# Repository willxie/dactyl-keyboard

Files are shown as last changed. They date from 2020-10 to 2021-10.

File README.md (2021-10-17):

# The Dactyl-ManuForm Keyboard - Python 3 - Cadquery
This is a fork of [Dactyl-Manuform](https://github.com/tshort/dactyl-keyboard) by Tom Short, which itself is a fork of [Dactyl](https://github.com/adereth/dactyl-keyboard) by Matthew Adereth, a parameterized, split-hand, concave, columnar, ergonomic keyboard.

While the code structure remains comparable to the original, Clojure and OpenSCAD have been replaced by Python and cadquery/OpenCASCADE.  The predecessors were exceptional contributions to the ergo keyboard community by the authors but used a rather esoteric programming language, Clojure, and a relatively inconsistent geometry engine, OpenSCAD.  My hope is that by converting the code the community will have an easier time modifying and evolving this design.  

## Collaborations and Donations
I decided to start accepting donations to help offset some of the prototyping costs and development time.  There are 2 ways to contribute to this project:

### Purchase a kit or keyboard from https://www.ergohaven.xyz/
I am also supported by [ergohaven](https://www.ergohaven.xyz/).  The Dactyl-Manuforms are generated from this repository.  After working with the owner on additions to support new features we decided to collaborate to evolve the designs they can offer and to support my work.  

### Donate directly
I opened Liberapay and Ko-fi accounts to accept donations.  It is obviously not necessary, but is appreciated.  If you do donate and have something specific you really want to see, please let me know. I want to be very open that I can't promise to complete all requests as there are many reasons like engine capabilities and generator construction that can make certain features unfeasible, but I will do my best to improve this repo for you and the ergo keyboard community.

Donate using Liberapay (https://liberapay.com/joshreve/donate)



## Helpful Feedback
At this point there has been tons of feedback form the community and I greatly appreciate it.  While I can only work on this in my free time, I do my best to respond to anyone who posts a comment or question.  Feedback on issues or just possible new features is always welcome.

## Updated Geometry Engine, generating STEP files
As part of the effort to create a new engine I converted the code to cadquery/OpenCASCADE.  While OpenSCAD has provided an open source 3D engine that is extremely popular, it frankly creates barely passable STLs when you have complex geometry.  After being extremely frustrated trying to fix the mesh I realized it is just not a stable engine to create high quality files.  OpenCASCADE is extremely powerful but requires extensive detail to operate.  cadquery provided an excellent platform to run a stable geometry engine with a simplified API. 

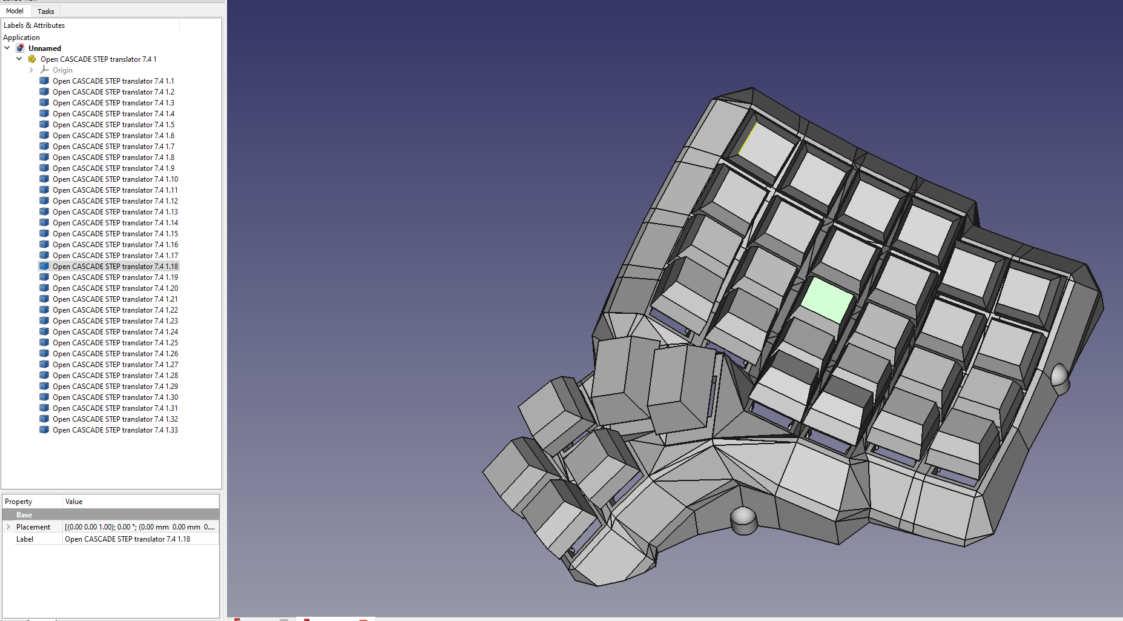
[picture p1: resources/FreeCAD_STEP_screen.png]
STEP File in FreeCAD


## Added Features

### Docker Autobuild
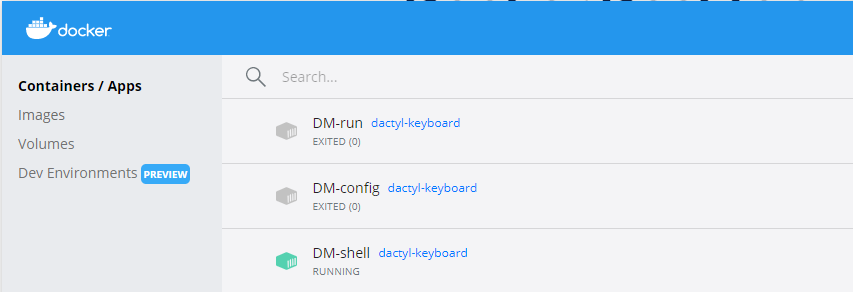
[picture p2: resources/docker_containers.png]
Docker Support!


At the excellent suggestion of [martint17r](https://github.com/joshreve/dactyl-keyboard/issues?q=is%3Apr+author%3Amartint17r) 
I have added docker configurations with a Windows batch file to assist with getting setup. 
If you have 
[docker desktop](https://www.docker.com/products/docker-desktop) installed, the batch file will create the 
dactyl-keyboard image and 4 containers:

- DM-run: runs `dactyl_manuform.py`, 
- DM-config: runs `generate_configuration.py`
- DM-shell: starts an interactive session to manually run from shell
  - tip: run bash after entering to get a better shell environment
- DM-release-build: runs `model_builder.py` to generate a number of keyboard variants

All apps bindmount the `src` and `things` directory to allow editing in the host and running in the
container.  While not exactly hard drive space efficient, this hopefully helps those having issues getting
cadquery running and prevents local Python conflicts.  It works well on my computer, but I don't use
docker often, so please let me know if you find any issues with the approach.

### Refactored

Your settings are now created by `generate_configuration.py` or by direct modification of the `run_config.json` file.  
This allows you to save `run_config.json` to share your configuration.

Additionally, the OpenSCAD/solid python and OpenCASCADE/cadquery versions are merged with separate helper functions 
to decouple the generator from the target library.  This also lets me stay sane by only modifying one file for most updates.
Running `dactyl_manuform.py` will automatically load the `run_config.json` file. 

### Everyone gets a thumb cluster!

Added support of for the thumb clusters in the [carbonfet Dactyl library](https://github.com/carbonfet/dactyl-manuform).
These are the "mini" and "carbonfet" thumb clusters. Additional trackball cluster added as well more info to be added after additional build and debug time.

Feel free to try them out with by setting `'thumb_style'` to 
`'DEFAULT'`, `'MINI'`, `'CARBONFET'`, `'MINIDOX'`, `'TRACKBALL_ORBYL'`, and `'TRACKBALL_CJ'`.

Trackball features accommodate a [Perixx PERIPRO-303](https://smile.amazon.com/gp/product/B08DD6GQRV/).  Others may fit, but this was the target ball diameter for the design.  It is a little smaller than a Ploopy to try to fit better in the cluster.

Rendered and actual images to be added in future commits.

### Clippable switch mounting

Tired of hot glue and constraining the socket with "nubs"?  I've added an adjustable undercut for using the clips on 
the sockets.  May require some tweaking and little filing, but I have my DM built without any glue and you can too.  
Just use `plate_style = 'UNDERCUT'`.  I've also added an improved local undercut using `plate_style = 'NOTCH'`.

### Kailh Hotswap
Added a new switch for hot swap and a way to include any additional geometry in the key plate by use of an imported file.
For hot swap just use `plate_style = 'HS_NOTCH'`, `plate_style = 'HS_HOLE'`, or `plate_style = 'HS_NUB'`.  
To import an arbitrary geometry set the `plate_file = None` and `plate_offset = 0.0`.  
The file must be .step for OpenCascade / cadquery and .stl for openSCAD / solid python.  
The zero reference should be the key center (XY), and the top of the plate (Z).  
Plate offset is a Z-axis translation for minor adjustments without modifying the geometry file.  

**DISCLAIMER:  I have not built the hot swap version and cannot speak to the geometry.  I found it running around in various places and don't know the origin.  At least one user has claimed it works.**  

If you know the origin I would like to credit the originator.  If you test it I'd love to know how well it works or if you come up with a better geometry I'm happy to add it.  

Message me on Reddit u/j_oshreve if you are really stuck.  I don't have much time to help, but can answer the occasional question.  Also feel free to put in a pull request if you come up with something crafty and want to give others access to it.

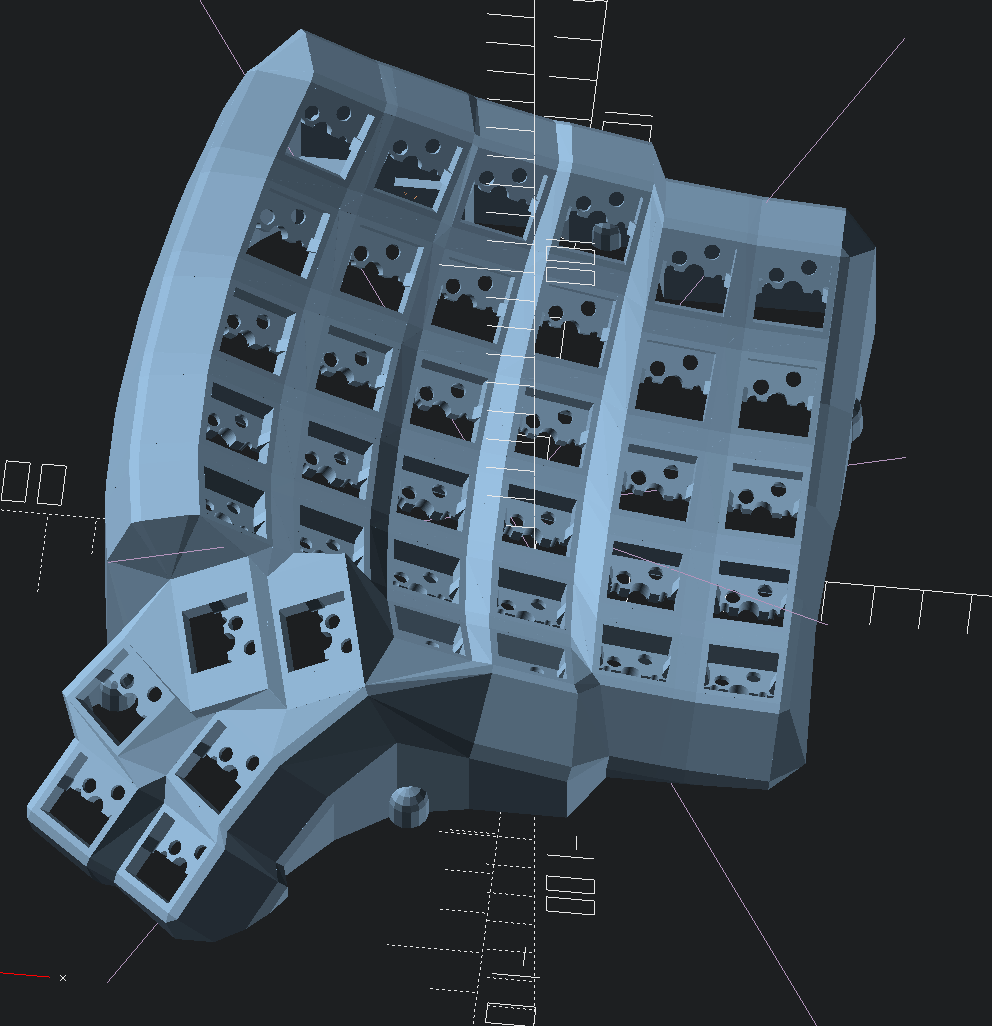
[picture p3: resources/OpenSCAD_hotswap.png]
Hot Swap in OpenSCAD


### Multiple Controller Mounts

Added an external mount for a separate controller tray.  Looks to work with lolligag's controller trays / holders:

- [Promicro V1](https://dactyl.siskam.link/loligagger-external-holder-promicro-v1.stl)
- [Promicro V2](https://dactyl.siskam.link/loligagger-external-holder-promicro-v2.stl)
- [Elite-C V1 ](https://dactyl.siskam.link/loligagger-external-holder-elite-c-v1.stl)

Just use `controller_mount_type = 'EXTERNAL'`.

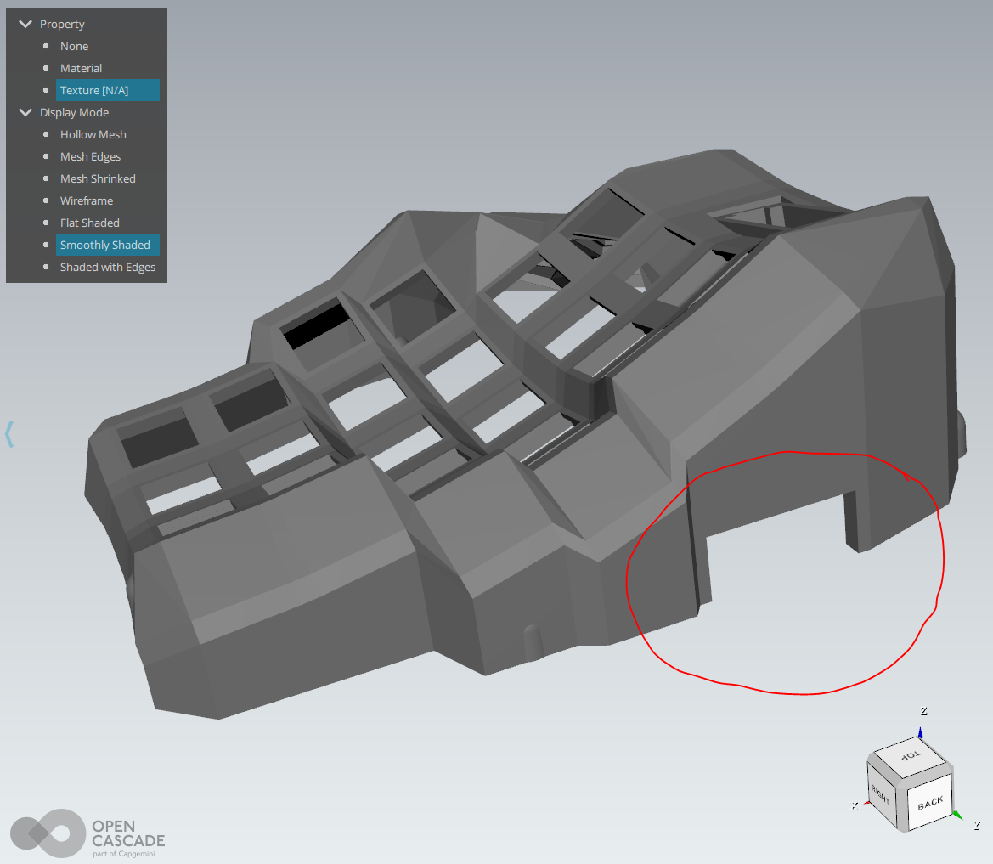
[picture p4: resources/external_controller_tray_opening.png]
Controller tray opening

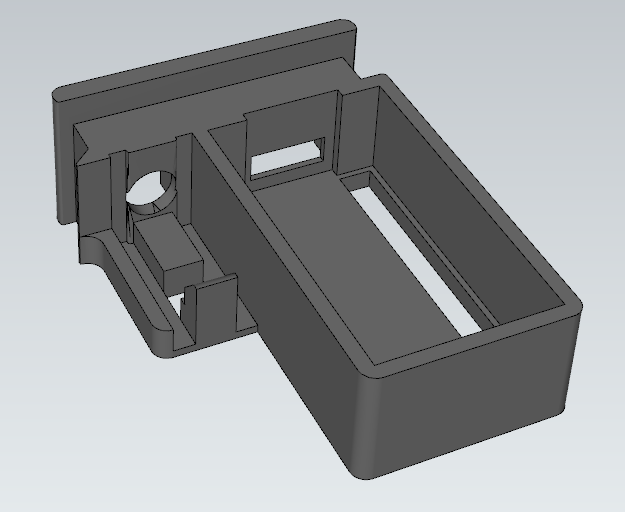
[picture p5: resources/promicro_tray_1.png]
Tray 1

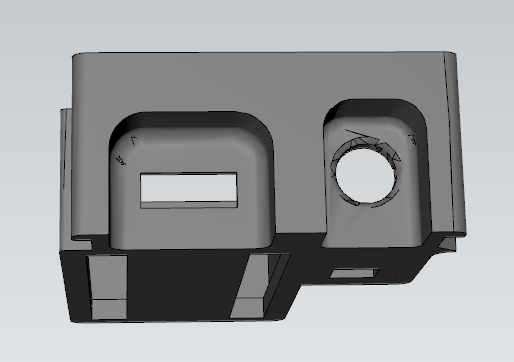
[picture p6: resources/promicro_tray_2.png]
Tray 2


This is a new feature so any feedback is appreciated.  If you have issues, message me on Reddit and I will try to help correct them.

### OLED Display Mount

Added 3 OLED mounts.  Have printed them stand alone with success.  I suggest clip, but it may require some tweaks based on your printer (over vs under sized).

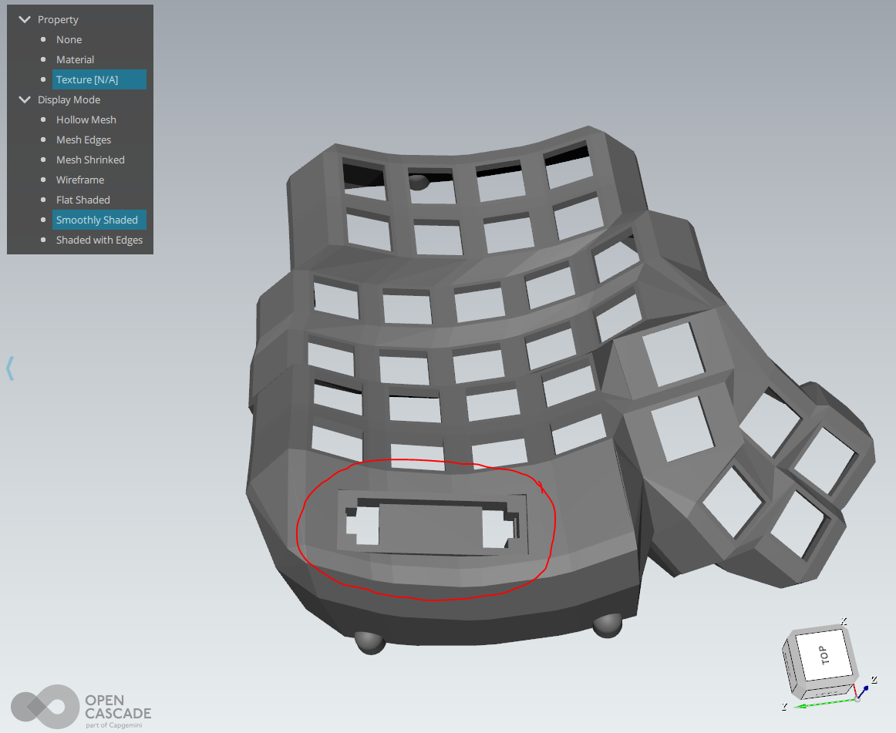
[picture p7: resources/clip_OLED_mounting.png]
OLED Clip Mounting

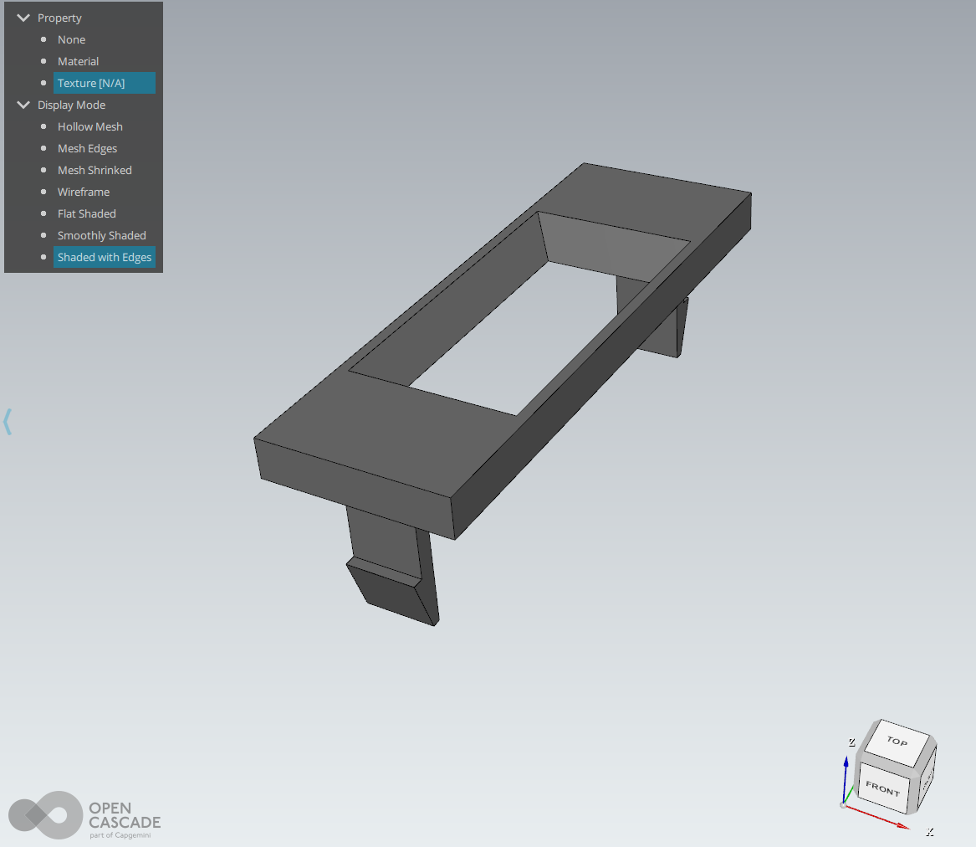
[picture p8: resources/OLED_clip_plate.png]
OLED Clip Plate


`oled_mount_type = 'CLIP'` creates an opening to set the OLED with a clip on face plate to hold it down.  This is the preferred mounting, but needs the OLED to have a removable connection.  

`oled_mount_type = 'SLIDING'` creates an opening such that you can slide the screen up through the back and into place.  Needs a piece of foam or a bit of glue to lock in place.

`oled_mount_type = 'UNDERCUT'` creates an opening with an undercut to create whatever custom holder you want.  Will not work without additional part creation from the user.

This is a new feature so any feedback is appreciated.  If you have issues, message me on Reddit and I will try to help correct them.  

### Screw Post Locations

You can now have slightly better control of screw mounts.  Set to `'screws_offset':'INSIDE'`, `'screws_offset':'OUTSIDE'` or `'screws_offset': 'ORIGINAL'` to control screw locations relative to the wall. 
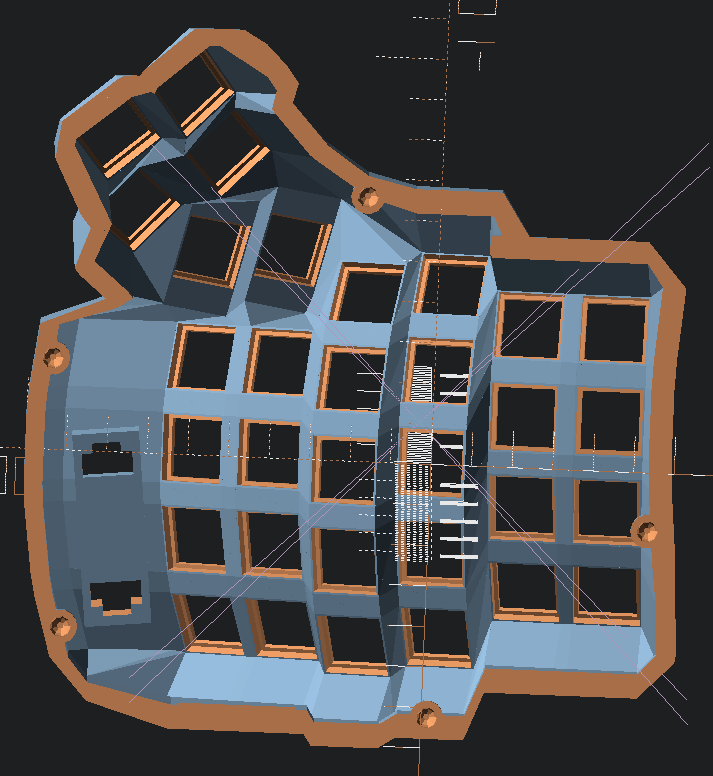
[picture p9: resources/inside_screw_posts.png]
Inside Screws


I am planning to deprecate outside and original at some point.  I don't see the need to carry all of them and the hidden look the best.  If you disagree feel free to let me know and I may keep a second form.

## Status / Future
This is now a bit of a monster of many minds and yet continues to bear fruit.  
I plan to continue to use this code to try new geometries and features to share for the foreseeable future.

## Installation

There are three different environments in which you can run this application. Depending on which you choose, the installation process will vary.

- [Docker Environment](#docker-environment-installation)
- [Conda Environment](#conda-environment-installation)
- [Python Environment](#python-environment-installation)

### Docker Environment Installation

Running the application with Docker is the most convenient way to do so. In addition to a straightforward installation, this also allows you to generate models in the background without having to keep a shell open.

*Note:* If you are using Windows, see [Docker Autobuild](#docker-autobuild).

Before you proceed, ensure you have installed [Docker](https://www.docker.com/) and the `docker` command is available from your terminal.

There are two tools you can use to help manage the Docker containers associated with this project. 

#### Make

If you prefer, you can use `make` to manage the containers. Type `make help` to see the available commands.

#### Bash Script

The `dactyl.sh` bash script provides a CLI to manage the containers. Type `./dactyl.sh --help` to see all CLI options.

In addition to the CLI you can run `./dactyl.sh` without any arguments to use an interactive menu. 

Upon running the script, you will be prompted to build the dactyl-keyboard Docker image.

Once the image is built, you can choose which containers to run on an as-needed basis. In general, you can start, stop, rebuild, inspect, and remove the containers via the CLI/Menu. 

You can also remove all of the Docker artifacts by running the included uninstaller.

*Tip:* Run `./dactyl.sh shell --session` to jump into a bash session inside of the shell container.

### Conda Environment Installation

After the Docker installation, Anaconda is the next best option. Before you begin, ensure you have installed [Anaconda](https://docs.anaconda.com/anaconda/install/index.html) and the `conda` command is available from your terminal.

You can install all of the dependencies by hand, but you can automate the install by running the bash script `./conda.sh`. This will create a python 3.7 environment named `dactyl-keyboard` and install all of the required dependencies.

If you would like to install into a conda environment manually, check the bash script to see all of the required commands.

If you would like to remove the conda artifacts, run `./conda.sh --uninstall`.

### Python Environment Installation

You can install the application in a regular python environment, but it is not recommended. You will not be able to take advantage of the updated geometry generated by the CadQuery engine, as this is only available via the Docker/Anaconda installation.

**Setting up the Python environment - NEW**
* [Install Python 3.X](https://www.python.org/downloads/release/python-385/) or use your [favorite distro / platform (Anaconda)](https://www.anaconda.com/products/individual) 
* It is advisable, but not necessary, to setup a virtual environment to prevent package/library incompatibility 
* [Install Numpy](https://pypi.org/project/numpy/), easiest method is `pip install numpy` or `pip3 install numpy` on linux.
* [Install dataclasses_json](https://pypi.org/project/dataclasses_json/), easiest method is `pip install dataclasses-json` or `pip3 install dataclasses-json` on linux.

**cadquery install**
* [Install scipy](https://pypi.org/project/scipy/), easiest method is `pip install scipy` or `pip3 install scipy` on linux.
* [Install cadquery](https://github.com/CadQuery/cadquery), many options (see link), but easiest method is `conda install -c conda-forge -c cadquery cadquery=2`.  Props to the creators/maintainers, this has the power of Open CASCADE with nearing the simplicity of OpenSCAD.

**OpenSCAD install**
* [Install SolidPython](https://pypi.org/project/solidpython/), easiest method is `pip install solidpython` or `pip3 install solidpython` on linux.
* [Install OpenSCAD](http://www.openscad.org/)

## Generating the design

**Generating the design - UPDATED**
* ~~Run `python dactyl_manuform_cadquery.py` or `python3 dactyl_manuform_cadquery.py`~~ 
* ~~Run `python dactyl_manuform.py` or `python3 dactyl_manuform.py`~~
* Run `generate_configuration.py` or directly edit `run_config.json` to configure the design
* Run `dactyl_manuform.py` to create the geometry (ENGINE variable in run determines method)
* This will regenerate the `things/` files (or in subdirectory if defined in config)
    * `*left.*`
    * `*right.*`
    * `*plate.*`
    * `*oled_clip.*` (if applicable)
    * `*oled_clip_test.*` (if applicable)
* Use OpenSCAD to open a `.scad` file
* Use FreeCAD or other application to open a `.step` file
* Make changes to design, repeat run step
* When done, use OpenSCAD or FreeCAD to export STL files

**The majority of the the rest of the below content is as defined by previous authors, except where noted.**

## Origin
Imgur

The main change is that the thumb cluster was adapted from the [ManuForm keyboard](https://github.com/jeffgran/ManuForm) ([geekhack](https://geekhack.org/index.php?topic=46015.0)). The walls were changed to just drop to the floor. The keyboard is paramaterized to allow adjusting the following: 

* Rows: 4 - 6 
* Columns: 5 and up
* Row curvature
* Column curvature
* Row tilt (tenting)
* Column tilt
* Column offsets
* Height

## Assembly

### Printing
Pre-generated files can be opened in OpenSCAD or FreeCAD and exported to STL.  Bottom plate is available as a step file or dxf for cadquery or a .scad file to be exported from OpenSCAD.

### Wiring

Here are materials tshort used for wiring.

* Two Arduino Pro Micros
* [Heat-set inserts](https://www.mcmaster.com/#94180a331/=16yfrx1)
* [M3 wafer-head screws, 5mm](http://www.metricscrews.us/index.php?main_page=product_info&cPath=155_185&products_id=455)
* [Copper tape](https://www.amazon.com/gp/product/B009KB86BU)
* [#32 magnet wire](https://www.amazon.com/gp/product/B00LV909HI)
* [#30 wire](https://www.amazon.com/gp/product/B00GWFECWO)
* [3-mm cast acrylic](http://www.mcmaster.com/#acrylic/=144mfom)
* [Veroboard stripboard](https://www.amazon.com/gp/product/B008CPVMMU)
* [1N4148 diodes](https://www.amazon.com/gp/product/B00LQPY0Y0)
* [Female RJ-9 connectors](https://www.amazon.com/gp/product/B01HU7BVDU/)

I wired one half using the traditional approach of using the legs of a diode to form the row connections. 
(I'm not great at soldering, so this was challenging for me.)
For this side, I used magnet wire to wire columns. That worked okay. 
The magnet wire is small enough, it wants to move around, and it's hard to tell if you have a good connection.

Imgur

For another half, I used stripboard for the row connections. 
This allowed me to presolder all of the diodes. 
Then, I hot-glued this in place and finished the soldering of the other diode ends. 
I like this approach quite a lot. 
Connections for the diodes were much easier with one end fixed down. 
On this half, I also used copper tape to connect columns. 
This worked a bit better than the magnet wire for me. 
For a future version, I may try just bare tinned copper wire for columns (something like #20). 
With the stripboard, it's pretty easy keeping row and column connections separate.

Imgur

Note that a telephone handset cable has leads that are reversed, so take this into account when connecting these leads to the controller.

The 3D printed part is the main keyboard. 
You can attach a bottom plate with screws. 
The case has holes for heat-set inserts designed to hold 3- to 6-mm long M3 screws. 
Then, I used wafer-head screws to connect a bottom plate. 
If wires aren't dangling, a bottom plate may not be needed. 
You need something on the bottom to keep the keyboard from sliding around. 
Without a plate, you could use a rubber pad, or you could dip the bottom of the keyboard in PlastiDip.

For more photos of the first complete wiring of v0.4, see [Imgur](http://imgur.com/a/v9eIO).

This is how the rows/columns wire to the keys and the ProMicro
Wire Diagram

#### Alternative row-driven wiring diagram for ProMicro:

NOTE: you also make sure the firmware is set up correctly (ex: change row pins with col pins)

Left Wire Diagram

Right Wire Diagram

### Firmware

Firmware goes hand in hand with how you wire the circuit. 
I adapted the QMK firmware [here](https://github.com/tshort/qmk_firmware/tree/master/keyboards/dactyl-manuform). 
This allows each side to work separately or together. 
This site also shows connections for the Arduino Pro Micro controllers.

## License

General Code Copyright © 2015-2021 Matthew Adereth, Tom Short, and Joshua Shreve
Mini thumb cluster Copyright © 2015-2018 Matthew Adereth, Tom Short, and Leo Lou
Carbonfet thumb cluster © 2015-2018 Matthew Adereth, Tom Short, and carbonfet (github username)

The source code for generating the models (everything excluding the [things/](things/) and [resources/](resources/) directories is distributed under the [GNU AFFERO GENERAL PUBLIC LICENSE Version 3](LICENSE).  The generated models and PCB designs are distributed under the [Creative Commons Attribution-NonCommercial-ShareAlike License Version 3.0](LICENSE-models).

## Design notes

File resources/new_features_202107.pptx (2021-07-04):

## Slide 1

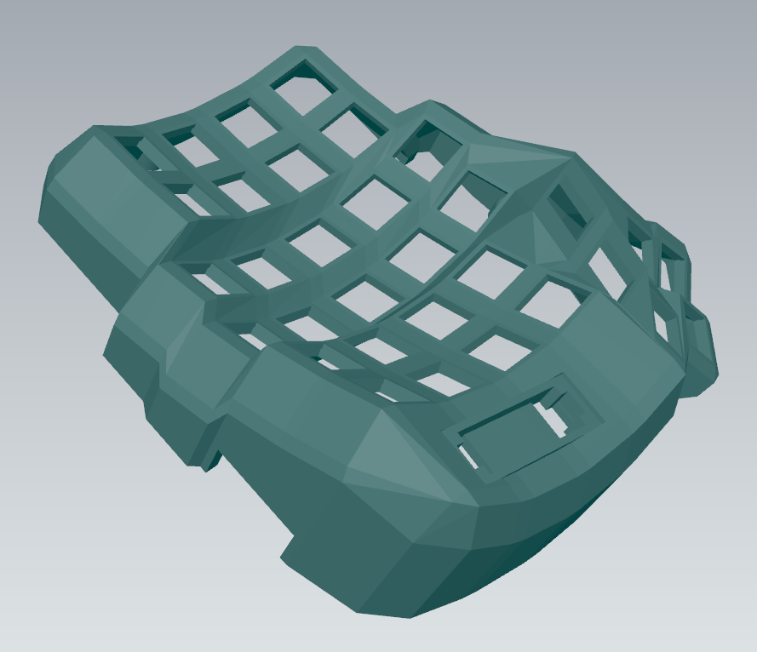
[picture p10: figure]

Controller Tray Interface

OLED Mounting

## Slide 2

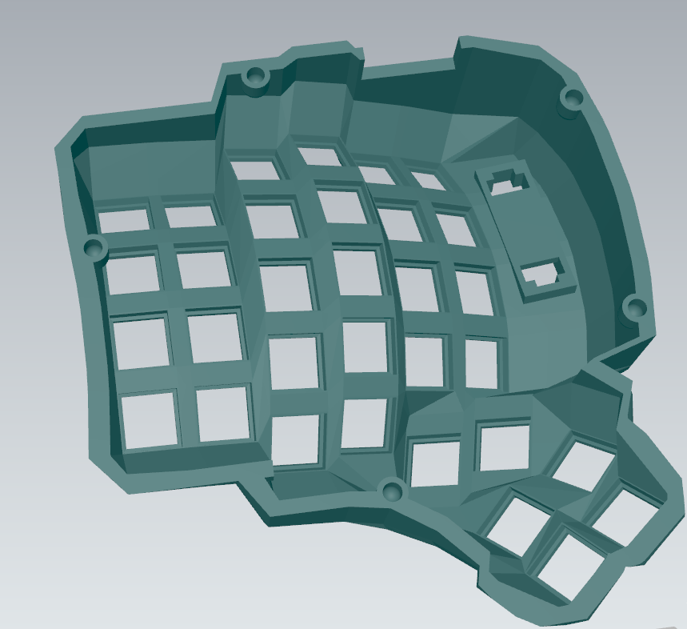
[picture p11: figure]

Controller Tray Interface

OLED Mounting

Internal Mount Screws

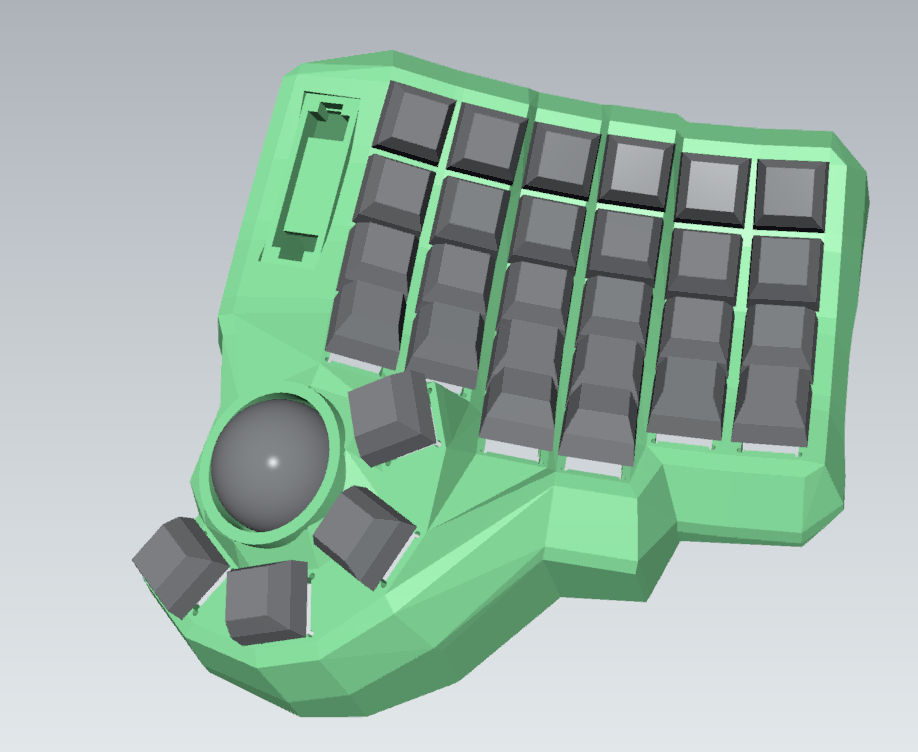
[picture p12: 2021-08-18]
resources/Trackball_JS_Cluster.PNG

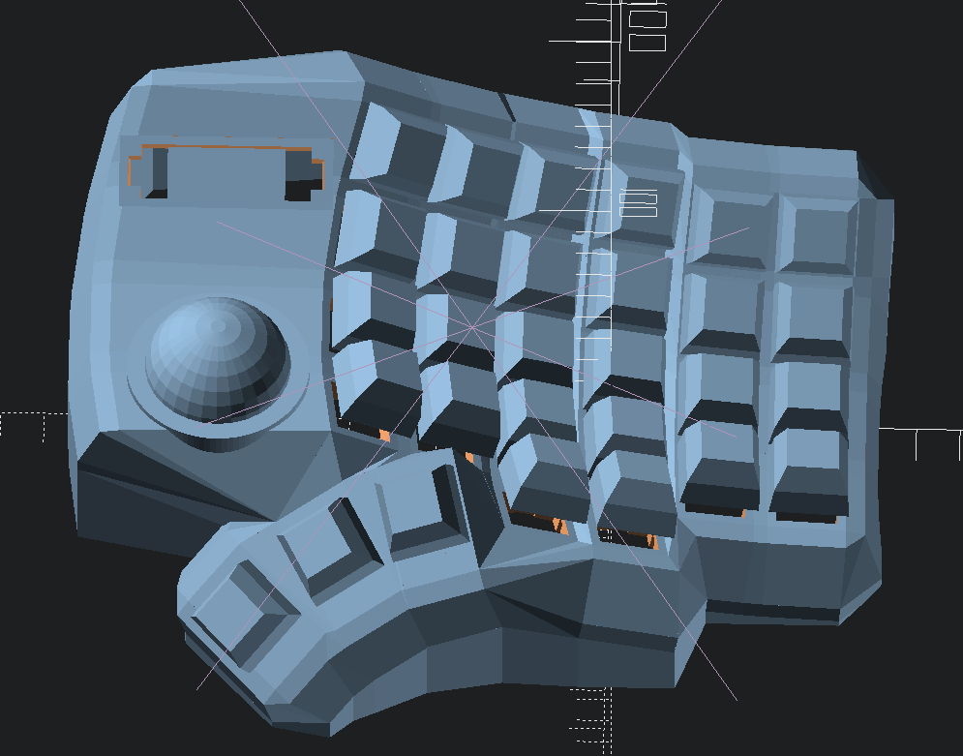
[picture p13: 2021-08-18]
resources/trackball_in_wall.png

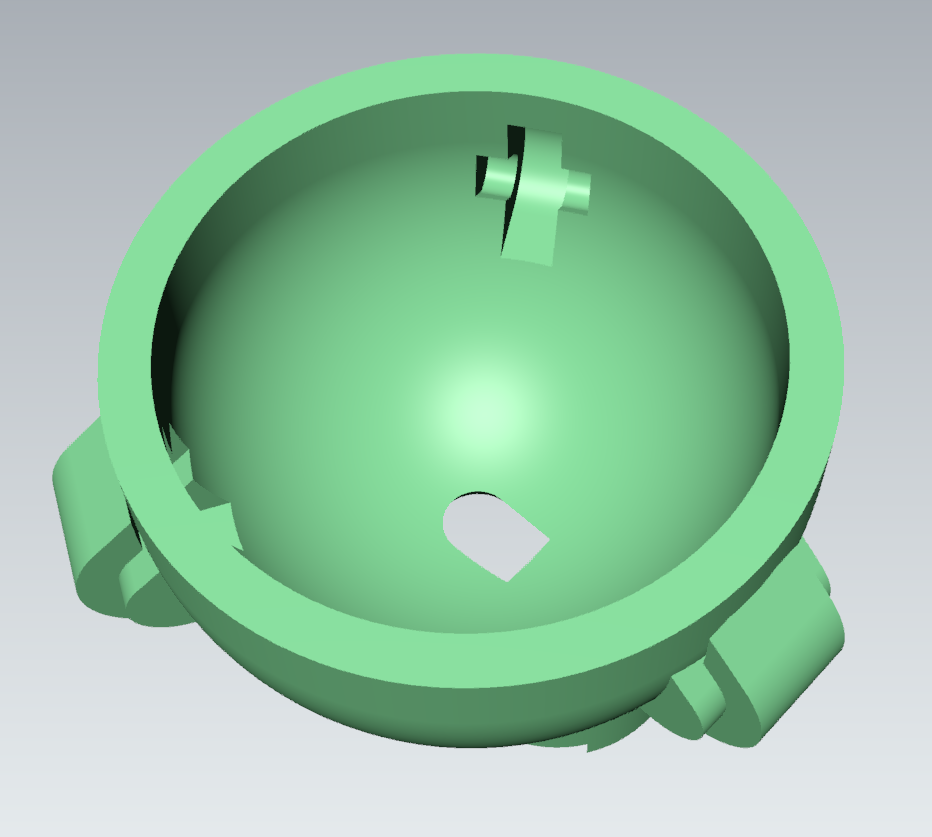
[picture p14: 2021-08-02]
resources/Trackball_socket.png

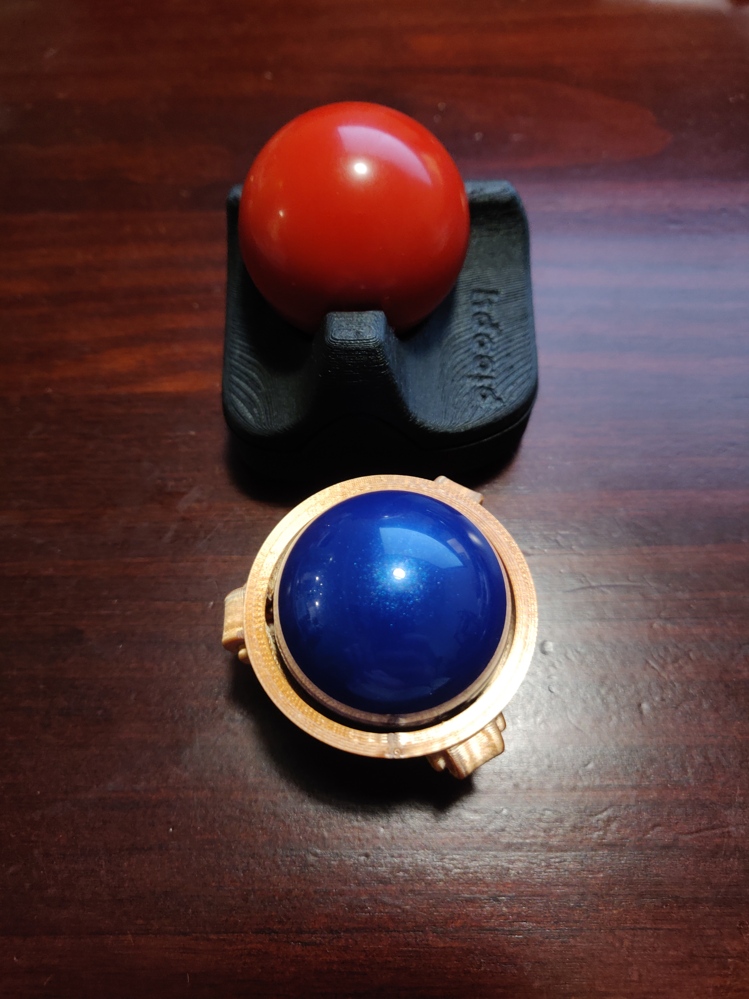
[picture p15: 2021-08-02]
resources/Trackball_socket_pic.jpg

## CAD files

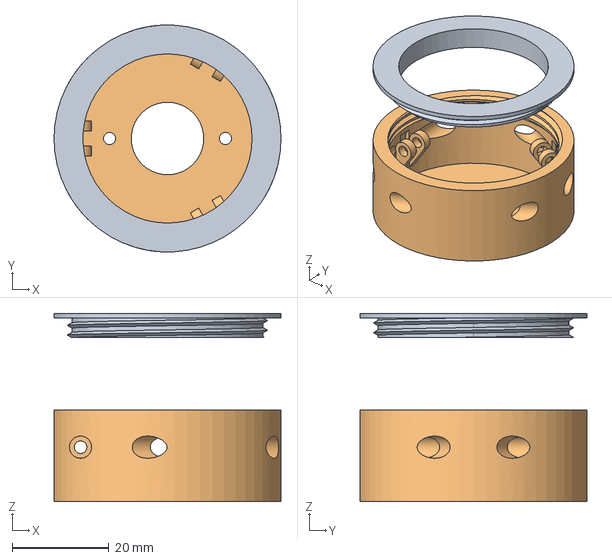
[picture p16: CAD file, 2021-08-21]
src/parts/trackball_mount.step
47.0 x 47.0 x 39.0 mm
Top
Bottom (1)

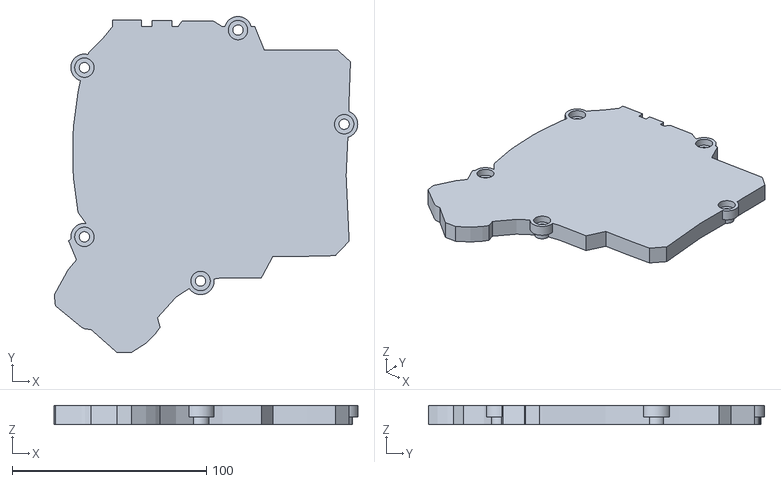
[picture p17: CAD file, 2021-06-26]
things/base_JAS.stl
156.4 x 173.1 x 10.0

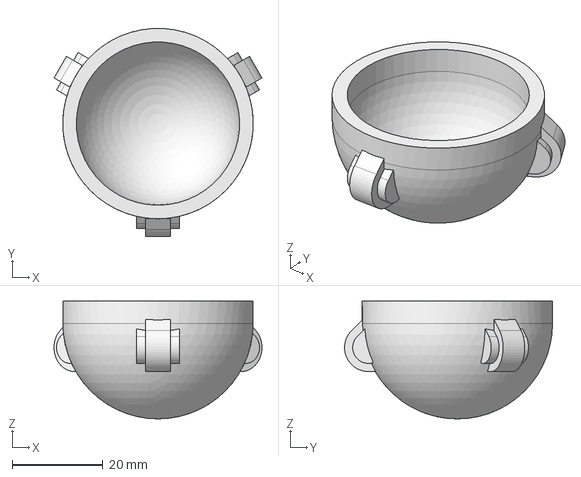
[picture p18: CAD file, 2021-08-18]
src/parts/trackball_socket_body_34mm.step
45.9 x 45.9 x 26.0 mm

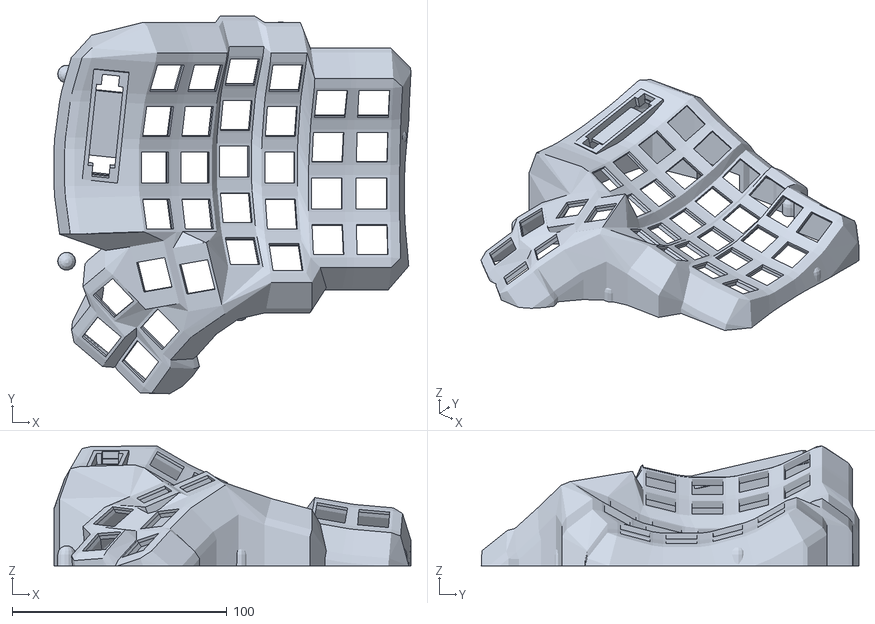
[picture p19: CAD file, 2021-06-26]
things/right_py.stl
166.3 x 175.9 x 55.9

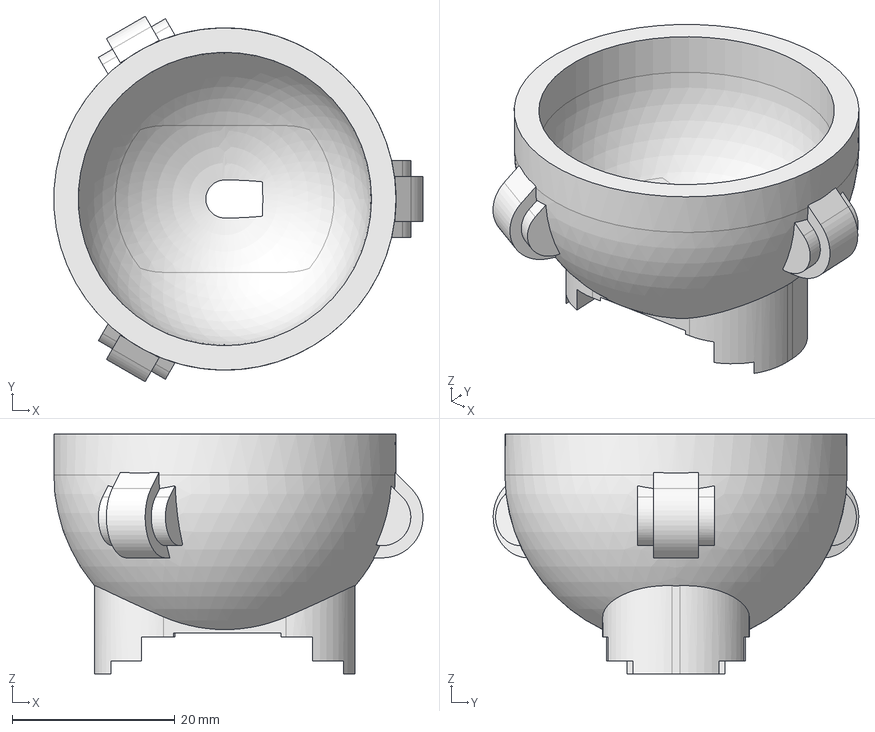
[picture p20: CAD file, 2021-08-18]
src/parts/trackball_fused_34mm.step
45.3 x 44.9 x 29.4 mm

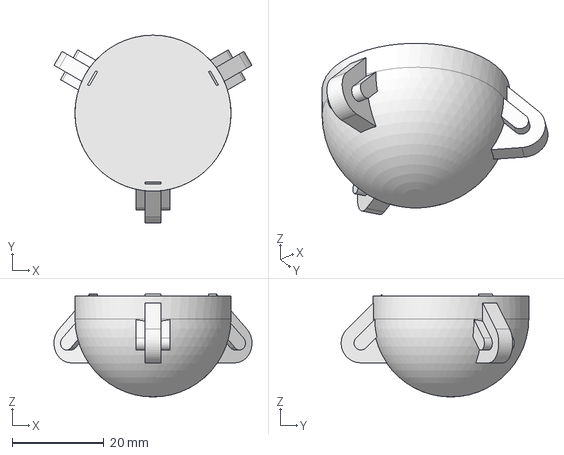
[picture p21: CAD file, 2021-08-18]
src/parts/trackball_socket_cutter_34mm.step
43.2 x 40.9 x 22.4 mm

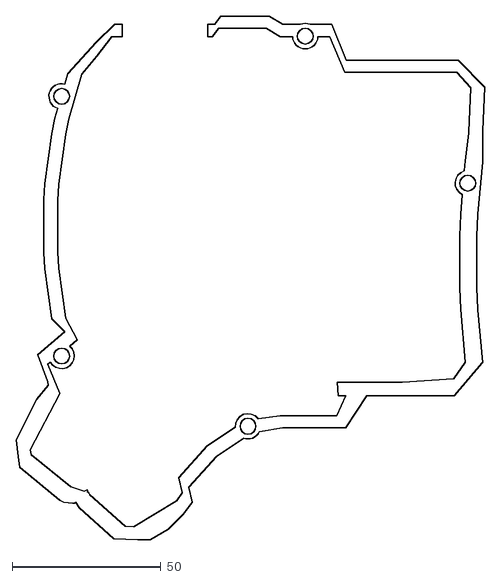
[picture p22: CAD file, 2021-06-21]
things/plate_og_py.dxf
157.4 x 175.9

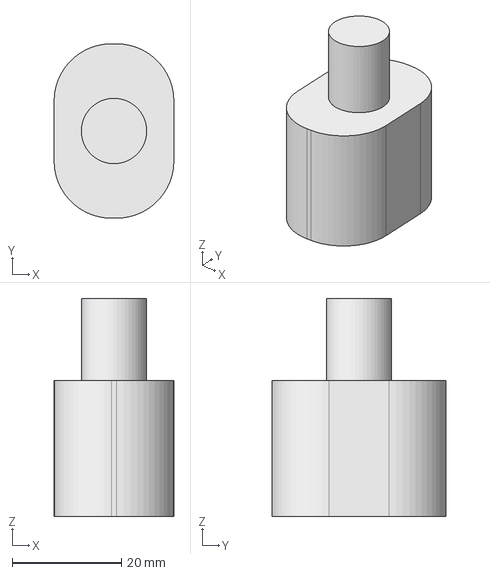
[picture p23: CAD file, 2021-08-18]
src/parts/trackball_sensor_cutter.step
22.0 x 32.0 x 40.0 mm

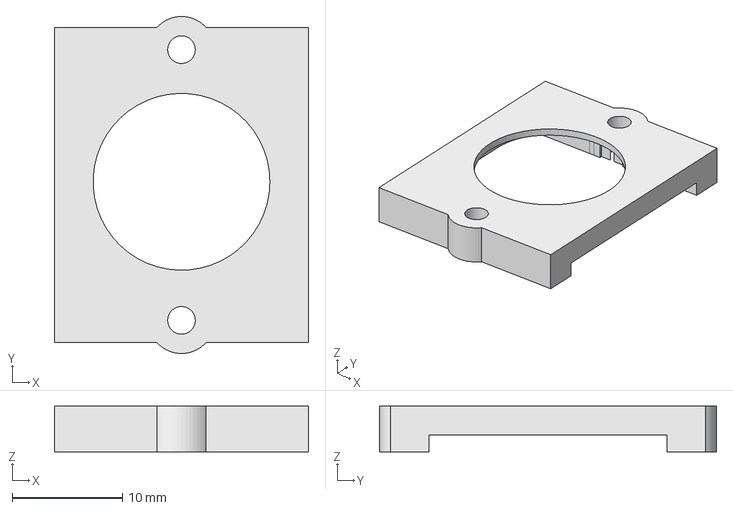
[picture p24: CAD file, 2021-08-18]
src/parts/sensor_holder.step
23.0 x 30.5 x 4.15 mm

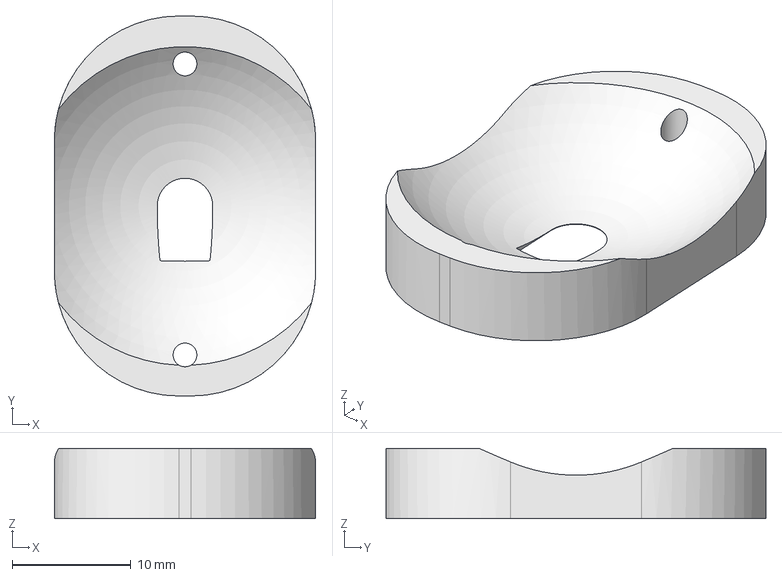
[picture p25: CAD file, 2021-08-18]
src/parts/trackball_sensor_mount.step
22.0 x 32.0 x 5.90 mm

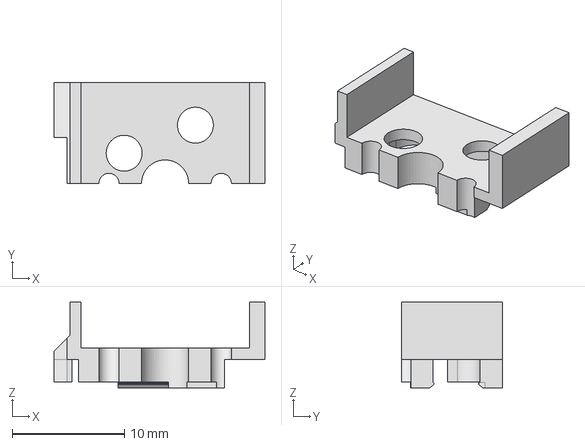
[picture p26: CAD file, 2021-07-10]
src/parts/hot_swap_plate.step
18.8 x 9.00 x 7.65 mm

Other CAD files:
things/plate_JAS.step
src/parts/hot_swap_plate.stl
src/parts/sensor_holder.stl
src/parts/trackball_fused_34mm.stl
src/parts/trackball_sensor_cutter.stl
src/parts/trackball_sensor_mount.stl
src/parts/trackball_socket_body_34mm.stl
src/parts/trackball_socket_cutter_34mm.stl
things/plate_JAS.FCStd

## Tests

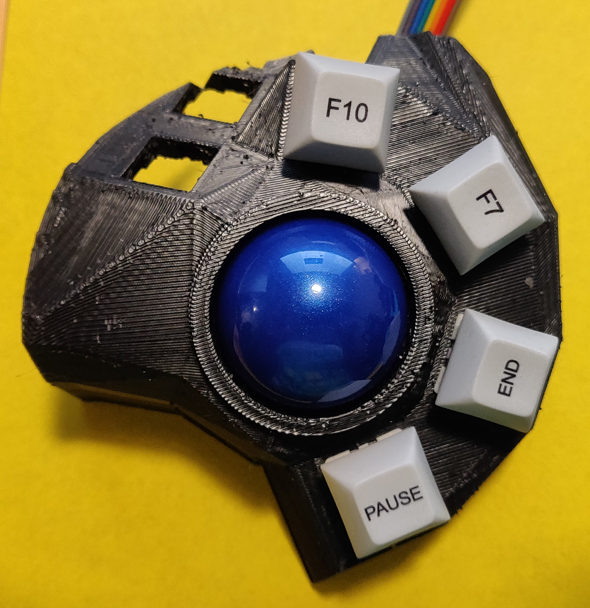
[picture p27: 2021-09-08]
resources/trackball_test.PNG

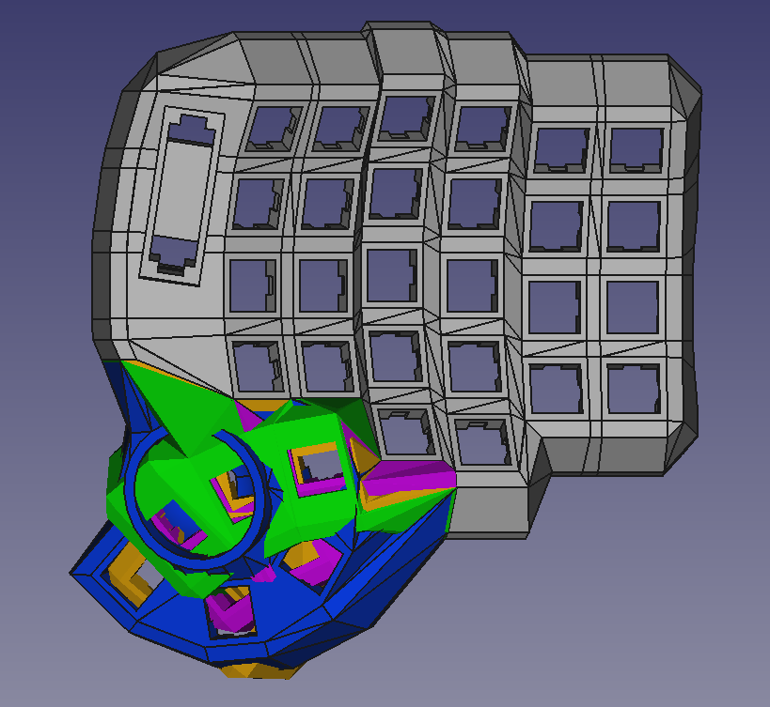
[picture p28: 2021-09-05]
resources/multithumb_test.PNG

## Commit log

2020-09-04 Added mising hotswap plate file. Still needs height verification on hotswap features relative to switch mount.
    [hot_swap_plate.stl]
2020-10-04 Minor changes to allow import of a key plate STL. Fixed RJ9 connector block.
2020-10-26 Added cadquery form of dactyl-manuform. Code is double translated (Clojure->Python, OpenSCAD->OpenCASCADE) and a mess but produces a .step file version of the dactyl-manuform design.
    [plate_og_py.dxf, plate_og_py.step]
2020-10-27 Removed extraneous plate function.
2021-03-28 Added hot swap and file import capabilities for modification of switch plates.
    [hot_swap_plate.step, hot_swap_plate.stl, hot_swap_plate_V01.FCStd]
2021-06-21 Upgrades for external controller trays / holders, undercuts for clipping in switch, and minor corrections to the right side wall. Minor refactoring of parameters for ease of interface.
    [plate_og_py.dxf, plate_og_py.step]
2021-06-26 Added multiple OLED mounts to OpenSCAD generator. Clip seems the most promising, but need user feedback. Will update cadquery version next.
    [base_JAS.stl, clip_oled_test.stl, oled_clip.stl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]
2021-06-28 Correction for OpenSCAD HS_NUB. Cleanup of export files. Generation of new files is the safest, but all files in things should now be consistent. May add more configurations if requested.
    [5x6_ctrl-tray_switch-undercut_OLED-clip_left.step, 5x6_ctrl-tray_switch-undercut_OLED-clip_left.stl, 5x6_ctrl-tray_switch-undercut_OLED-clip_plate.dxf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]
2021-07-03 Large change to things directory with pregenerated files in multiple configurations. Implemented prebuild generator to automatically create pregenerated files.
    [4x5_Basic_left.step, 4x5_Basic_plate.dxf, 4x5_Basic_plate.step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]
2021-07-03 Cadquery set to plate only in previous commit, fixed to create all geometry. Added features for screw mount positions.
2021-07-05 Mid-change commit. Added DM mini and carbonfet thumb clusters. Still tweaking screw locations and relative OLED, etc. Commiting to share progress.
2021-07-06 Updated cadquery with additional thumb clusters. Base form looks good. Need to check secodnary features (screws, tray, OLED) for compatibility.
2021-07-08 Temporary version as the cadquery and solid python versions are merged by use of helper functions. Added a screw to the thumb cluster. Cadquery baseplate now has counterbores and actual solid geometr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
2021-07-08 Key plate screw holes and added key plate notches for snapping in switches rather than a giant undercut.
2021-07-09 Added helper files to remove the cadquery / solid python helpers from the main file. Improved notch and added holes around key plate for mounting. Still WIP, but should be functional.
2021-07-10 Minor updates and cleanup. Biggest improvement is using relative reference for OLED placement to minimize tweaks on structural and row/column count changes. Looking for one more commit for minor twea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
    [hot_swap_plate.step, hot_swap_plate.stl, hot_swap_plate_V02.FCStd]
2021-07-13 Minor fixes for missing web on MINI thumb cluster. Added readme content and options for USB out only and no connector / controller features.
    [hot_swap_plate_V02.FCStd]
2021-07-14 updates for rotating plates on thumb cluster. Created due to crowding of hotswap and other issues.
2021-07-15 Amended thumb_post corner placement functions to eliminate void created by plate_rim != 3. Dependant variables relocated. Tested default.
2021-07-17 Added docker capabilities and profile including batch file execution. If there is expressed interest I can add a linux .sh file as well to simplify image and container/app creation. Also, minor fixes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
2021-07-25 Fixes to default cluster. Some key shifts. Removing outputs from repo. Will be moving many outputs to releases shortly. If there are issues, use previous commit.
    [4x5_Basic_left.step, 4x5_Basic_right.step, 4x5_CtrlTray_left.step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]
2021-07-25 Allow oled_mount_type to be "NONE" as well as None.
    This makes it possible to remove the OLED mount from the .json file.
2021-07-26 Fixed minor gaps in carbonfet cluster due to other fixes to default cluster. Fixed screw_cbore_diameter which was applied as a radius, doubling the hole size.
2021-07-28 Final minidox fixes for screw placement.
2021-07-30 Fixed keyswitch nubs. Error came from code consolidation between cadquery and solid python. One centered the cylinder, the other generated it in the positive Z direction. Both now fully center the cy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
2021-08-02 Update to add release builds. Should make a large number of prebuilts for people to look at. Also fixed minor issues.
    [4x5_Basic_plate.dxf, 4x5_Basic_plate.step, 4x5_CtrlTray_plate.dxf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]
2021-08-04 Add trackball
    [trackball_mount.step]
2021-08-05 Interim commit with partially functioning trackball. trackball in wall is mostly working (still WIP), trackball cluster has layout but no webs or walls.
    [ball_socket_v00.step, ball_socket_v00.stl]
2021-08-06 Adding CAD geometry. Debugging minor issues.
    [trackball_fused_34mm.step, trackball_fused_34mm.stl, trackball_sensor_cutter.step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]
2021-08-06 Minor mods, CAD trackball socket in models.
2021-08-12 Interim checkin. Initial version of trackball webs/walls in, still working on component cut/union order. Fixed base plates and walls to be identical in caquery and solid. Fixed if/elif/else structure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
2021-08-16 Trackball updates. Still need to refresh geometry. Optical distance is too long.
    [trackball_only_V09.FCStd]
2021-08-18 File cleanup.
    [ball_socket_v00.step, ball_socket_v00.stl, hot_swap_plate_V01.FCStd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]
2021-08-19 added a 'build' command
    also removed check for a command argument; just let an empty command fall through to the default case
2021-08-19 moved parts to their own directory
    also fixed bug that would not correctly inlcude parts for configs with a `save_dir` set to a subdirectory of the things directory
    [hot_swap_plate.step, hot_swap_plate.stl, sensor_holder.step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]
2021-08-20 Fixes to base plate and screw mount "handedness" and baseplate mirroring. Minor fix to trackball in wall rotations.
2021-08-21 moved file and slow progress to blender engine.
    [trackball_mount.step]
2021-08-22 Fixed docker directories in batch file.
    Added note for when run_config is used vs. configuration argument.
    [base_JAS.stl, plate_JAS.FCStd, plate_JAS.step]
2021-09-03 Added PCB controller mount feature options.
    Also, working on modular trackball, though ball bearings make it difficult to decouple as they typically land in the middle of the walls and webs.
2021-09-05 Added separable thumbs and cleaned up all the connections and thumb connections.
    Added separable thumbs and cleaned up all the connections and thumb connections.
    Thumb connections previously contained what should be in the finger connections.
    Added extra screws for separable thumb config to secure it. Previously had one screw.
2021-09-07 Update trackball_sensor_mount.stl
    I fixed the non-manifold geometry in the sensor mount which causes openscad to fail to render TBIW configurations/
    [trackball_sensor_mount.stl]
2021-09-08 Separable thumb improvements. PCB clearance cuts.
2021-10-24 Fixed cadquery package requirement.
    Reverted the geometry generation that was compensating for the wrong
    cadquery version. Uncertain why the versions were dramatically
    different, will have to watch carefully on new releases or considering
    switching environment to a specific version of cadquery instead of
    "master".
2021-11-26 bug fix for pcb_clear on default cluster when not intended.
2021-11-26 Bug fix for holes in the non-1U default thumb cluster.
2021-11-28 Update build_docker.bat
    Fixed docker mount directories to include whole project to prevent the need to specifically call out any added directories.
2022-03-25 Update environment.yml
    Quick fix for docker failure due to cadquery package conflicts. May have to adjust after testing, but current file always fails so is at least an improvement.
2022-05-06 0506 print settings
2022-05-12 Low profile test print
2022-05-12 Prototype 2
2022-05-16 Final versoin for matte print
